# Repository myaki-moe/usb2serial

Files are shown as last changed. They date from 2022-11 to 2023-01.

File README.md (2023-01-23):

# usb2serial

A low cost open source USB to 3 port serial (2*UART + 1*DBUS) adapter.

Based on STM32F103 (blue pill) and bluepill-serial-monster firmware, usb2serial supports USB CDC protocol for plug and play (PnP).

低成本开源USB到三路串口 (2*UART + 1*DBUS) 转换器. 

基于STM32F103 (blue pill) bluepill-serial-monster固件, usb2serial支持基于USB CDC协议的即插即用.

## Quick Start | 快速开始

1. PCB proofing using GERBER file `usb2serial_pcb/gerber/`
2. SMD or hand soldering using [ibom](usb2serial_pcb/bom/ibom.html)
3. Build bluepill-serial-monster firmware
4. Pull-up BOOT0 and reset MCU to enter bootloader.
5. Flash the firmware using [stm32flash](https://sourceforge.net/p/stm32flash) from UART1
6. Testing

```bash
# connect TX and RX first
# list all serial device
ls /dev/ttyACM*
# do a loopback test
minicom -D /dev/ttyACM{YOUR_DEVICE_NUMBER}
```

1. 使用GERBER文件 `usb2serial_pcb/gerber/` 打样PCB
2. SMT或使用 [ibom](usb2serial_pcb/bom/ibom.html)手工焊接
3. 编译bluepill-serial-monster固件
4. 拉高BOOT0进入烧录模式
5. 使用 [stm32flash](https://sourceforge.net/p/stm32flash) 从UART1烧录固件
6. 测试

```bash
# connect TX and RX first
# list all serial device
ls /dev/ttyACM*
# do a loopback test
minicom -D /dev/ttyACM{YOUR_DEVICE_NUMBER}
```

## Toolchains | 工具链

* PCB Design: KiCad 6.0.9
* Complier: arm-none-eabi-gcc 12.2.0
* Firmware Programmer: [stm32flash](https://sourceforge.net/p/stm32flash) 0.7

* PCB设计: KiCad 6.0.9
* 编译器: arm-none-eabi-gcc 12.2.0
* 固件烧录: [stm32flash](https://sourceforge.net/p/stm32flash) 0.7

## License | 许可证

* The USB2CAN project is released under GPLv3 license.

* The bluepill-serial-monster project is released under MIT license.

* USB2CAN项目基于GPLv3协议发布

* bluepill-serial-monster项目基于MIT协议分发

## Related Projects | 相关项目

[bluepill-serial-monster](https://github.com/r2axz/bluepill-serial-monster)

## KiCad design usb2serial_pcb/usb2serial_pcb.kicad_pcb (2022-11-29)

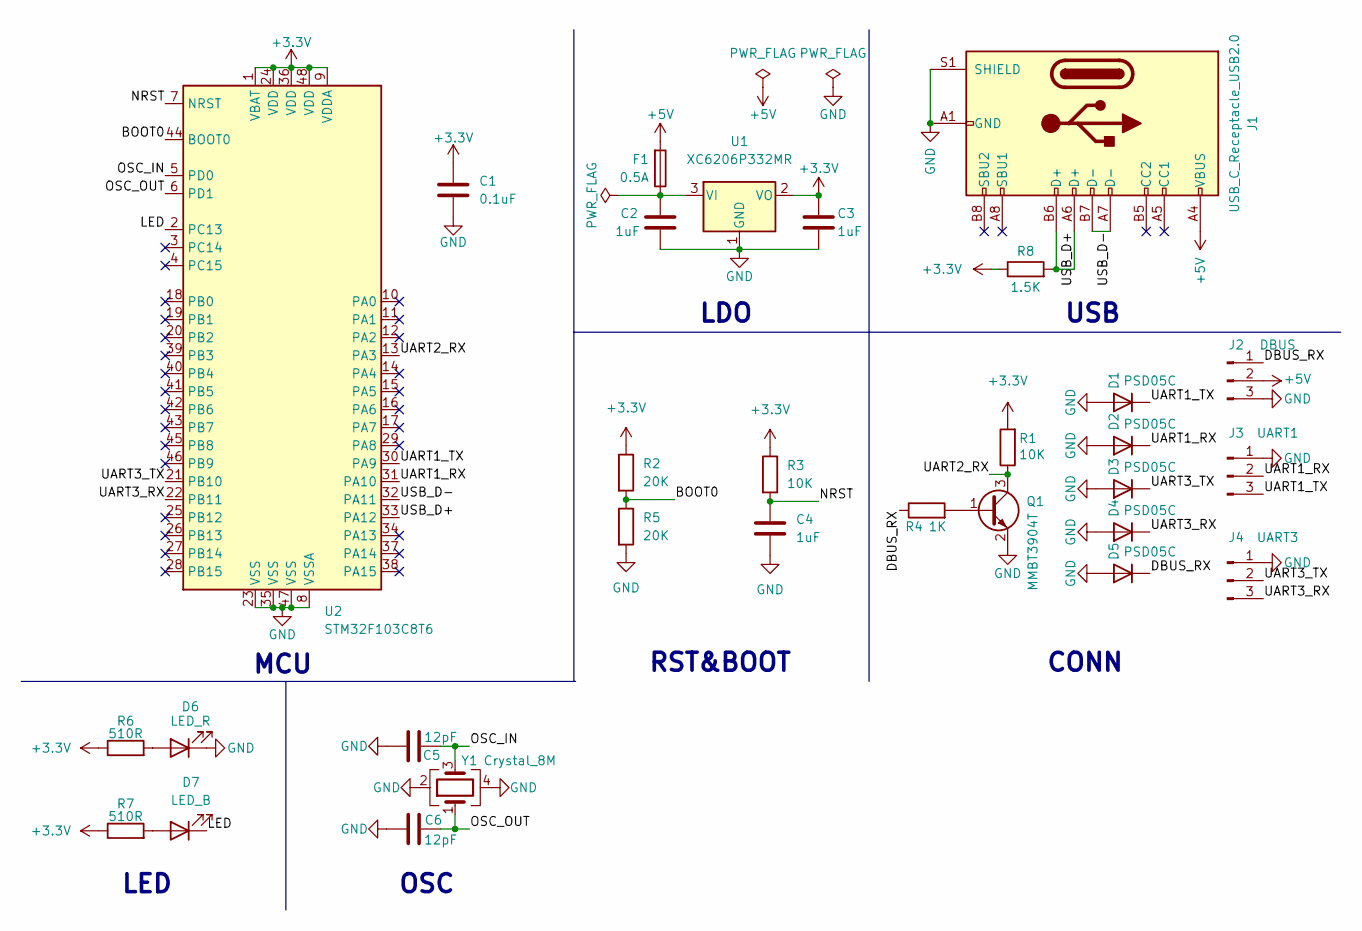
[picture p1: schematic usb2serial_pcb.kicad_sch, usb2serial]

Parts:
C1: 0.1uF; C_0402_1005Metric
C2, C3, C4: 1uF; C_0402_1005Metric
C5, C6: 12pF; C_0402_1005Metric
D1, D2, D3, D4, D5: PSD05C; D_SOD-323
D6: LED_R; D_0402_1005Metric
D7: LED_B; D_0402_1005Metric
F1: 0.5A; Fuse_0603_1608Metric
J1: USB_C_Receptacle_USB2.0; USB_C_Receptacle_Palconn_UTC16-G
J2: DBUS; PinHeader_1x03_P2.54mm_Horizontal
J3: UART1; JST_GH_SM03B-GHS-TB_1x03-1MP_P1.25mm_Horizontal
J4: UART3; JST_GH_SM03B-GHS-TB_1x03-1MP_P1.25mm_Horizontal
Q1: MMBT3904T; SOT-523
R1, R3: 10K; R_0402_1005Metric
R2, R5: 20K; R_0402_1005Metric
R4: 1K; R_0402_1005Metric
R6, R7: 510R; R_0402_1005Metric
R8: 1.5K; R_0402_1005Metric
U1: XC6206P332MR; SOT-23
U2: STM32F103C8T6; LQFP-48_7x7mm_P0.5mm
Y1: Crystal_8M; Crystal_SMD_3225-4Pin_3.2x2.5mm

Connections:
+3.3V: C1.1, C3.1, R1.2, R2.1, R3.1, R6.1, R7.1, R8.1, U1.2 (VO), U2.1 (VBAT), U2.9 (VDDA), U2.24 (VDD), U2.36 (VDD), U2.48 (VDD)
+5V: F1.2, J1.A4 (VBUS), J1.A9 (VBUS), J1.B4 (VBUS), J1.B9 (VBUS), J2.2
/BOOT0: R2.2, R5.1, U2.44 (BOOT0)
/DBUS_RX: D5.1 (K), J2.1, R4.1
/LED: D7.1 (K), U2.2 (PC13)
/NRST: C4.1, R3.2, U2.7 (NRST)
/OSC_IN: C5.2, U2.5 (PD0), Y1.3
/OSC_OUT: C6.2, U2.6 (PD1), Y1.1
/UART1_RX: D2.1 (K), J3.2, U2.31 (PA10)
/UART1_TX: D1.1 (K), J3.3, U2.30 (PA9)
/UART2_RX: Q1.3 (C), R1.1, U2.13 (PA3)
/UART3_RX: D4.1 (K), J4.3, U2.22 (PB11)
/UART3_TX: D3.1 (K), J4.2, U2.21 (PB10)
/USB_D+: J1.A6 (D+), J1.B6 (D+), R8.2, U2.33 (PA12)
/USB_D-: J1.A7 (D-), J1.B7 (D-), U2.32 (PA11)
GND: C1.2, C2.1, C3.2, C4.2, C5.1, C6.1, D1.2 (A), D2.2 (A), D3.2 (A), D4.2 (A), D5.2 (A), D6.1 (K), J1.A1 (GND), J1.A12 (GND), J1.B1 (GND), J1.B12 (GND), J1.S1 (SHIELD), J2.3, J3.1, J4.1, Q1.2 (E), R5.2, U1.1 (GND), U2.8 (VSSA), U2.23 (VSS), U2.35 (VSS), U2.47 (VSS), Y1.2, Y1.4
unnamed: C2.2, F1.1, U1.3 (VI)
unnamed: D6.2 (A), R6.2
unnamed: D7.2 (A), R7.2
unnamed: Q1.1 (B), R4.2

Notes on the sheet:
LED
CONN
RST&BOOT
USB
OSC
LDO
MCU

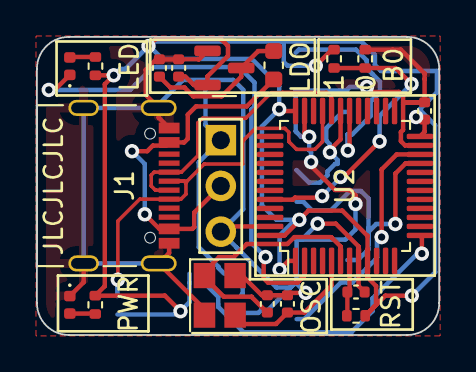
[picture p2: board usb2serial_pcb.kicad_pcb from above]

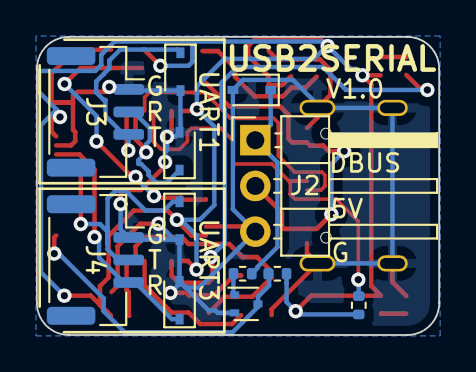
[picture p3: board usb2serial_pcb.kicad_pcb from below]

Board: 2 copper layers, 22.4 x 16.6 mm, 30 parts (12 on the bottom side), 20 nets.

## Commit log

2022-11-14 add pcb design V1.0
    [usb2serial_pcb.kicad_pcb, usb2serial_pcb.kicad_sch]
2022-11-14 add gerber and ibom
    [usb2serial_pcb-B_Cu.gbr, usb2serial_pcb-B_Mask.gbr, usb2serial_pcb-B_Paste.gbr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]
2022-11-29 add pull up register for USB enum
    [usb2serial_pcb-B_Cu.gbr, usb2serial_pcb-B_Mask.gbr, usb2serial_pcb-B_Paste.gbr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]
